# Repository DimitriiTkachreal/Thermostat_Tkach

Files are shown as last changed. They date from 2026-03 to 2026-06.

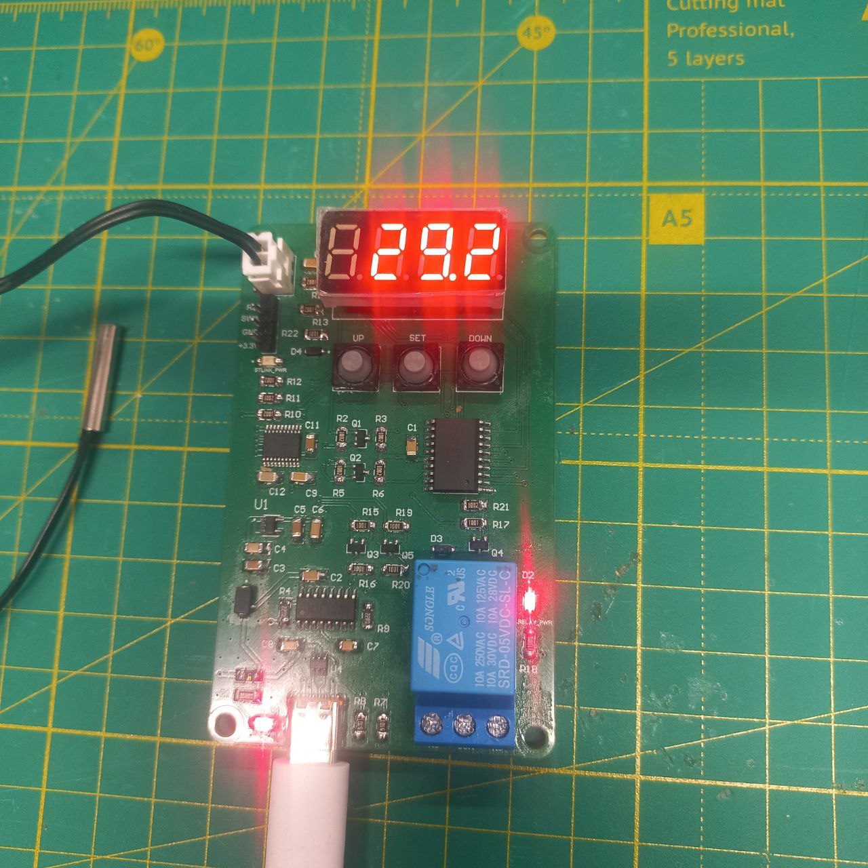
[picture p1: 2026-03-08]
Docs/Photo1.jpg

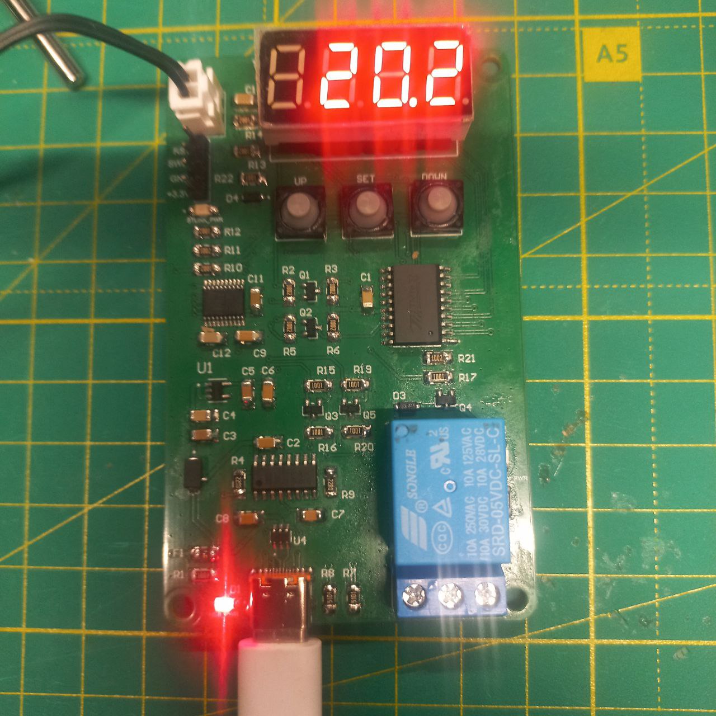
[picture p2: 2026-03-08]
Docs/Photo2.jpg

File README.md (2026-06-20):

# Thermostat STM8 v1.0

**Автор:** Ткач Дімітрій (@ld_td7) | **Email:** lidergsm1466@gmail.com  
**Дата:** 30.08.2025  

## Опис проєкту
Цифровий термостат реального часу на базі 8-бітного мікроконтролера STM8. Проєкт є функціональним аналогом популярного модуля W1209. Прошивка написанау у стилі Bare-Metal мовою C (стандарт C89, компілятор COSMIC) без використання сторонніх бібліотек. Розроблено в рамках стажування Ajax.

### Апаратна частина
* **MCU:** STM8S103F3P6 (16 MHz, 1KB RAM, 8KB Flash, 640 bytes EEPROM).
* **Живлення:** USB Type-C (5V). Логіка мікроконтролера живиться від 3.3V через лінійний стабілізатор AP2112K-3.3TRG1. Для зменшення навантаження на стабілізатор, силова частина та периферія живляться безпосередньо від 5V.
* **Узгодження рівнів:** Оскільки МК працює на 3.3V, а дисплей та UART на 5V, на лініях даних встановлено двонаправлені конвертери логічних рівнів.
* **Сенсор:** NTC термістор 10kΩ (B3950) + резистор 10kΩ (дільник напруги). Підключений до піна **PC4** (АЦП канал 2, вхід налаштовано як Floating).
* **Дисплей:** 4-розрядний 7-сегментний LED-індикатор з драйвером TM1637. Підключений до **PC6 (DIO)** та **PC7 (CLK)**. Піни налаштовані в режим Open-Drain із зовнішніми підтяжками.
* **Керування:** 3 тактові кнопки (SET - **PC5**, UP - **PD2**, DOWN - **PD3**). Налаштовані як Floating входи, оскільки на платі розведені зовнішні підтягуючі резистори 10kΩ до 3.3V.
* **Вихідний каскад:** Електромеханічне реле (керується через пін **PC3**, режим Push-Pull).
* **Дебаг:** Вбудований USB-UART міст CH340C. Прошивання мікроконтролера, через ST-Link v2.

## Інструкція з користування
Керування здійснюється кнопками: `SET`, `UP`, `DOWN`.
У робочому режимі дисплей відображає поточну температуру в приміщенні. Якщо температура виходить за межі встановлених лімітів, МК подає логічну одиницю на реле для увімкнення нагріву/охолодження (загоряється відповідний індикатор). Для швидкої зміни цільової температури коротко натисніть `SET`. Якщо датчик пошкоджено або температура виходить за межі вимірювання, пристрій переходить у захист і відображає `Err` або `ALrM`.

### Меню налаштувань
Для входу у глибокі налаштування утримуйте кнопку **SET** більше **1 секунди**.
* **Навігація:** `UP` / `DOWN` перемикають параметри (P0...P6).
* **Редагування:** Натисніть `SET` для вибору, змініть значення кнопками `UP`/`DOWN`, натисніть `SET` для збереження в енергонезалежну пам'ять.
* **Вихід:** Зачекайте 10 секунд (автовихід).

#### 📋 Карта параметрів
| Код | Назва параметра |  Опис функції І | Фізичний діапазон МК | Заводське |
|:---:|:---|:---|:---:|:---:|
| **P 0** | **Mode** | Режим роботи термостата | `0` (Нагрів) / `1` (Охолодження) | `0` |
| **P 1** | **Hysteresis** | Гістерезис (різниця вкл/викл) | 0.1 ... 15.0 °C | 2.0 °C |
| **P 2** | **Max Limit** | Обмеження максимальної температури | -20.0 ... 120.0 °C | 80.0 °C |
| **P 3** | **Min Limit** | Обмеження мінімальної температури | -20.0 ... 120.0 °C | -20.0 °C |
| **P 4** | **Calibration**| Калібрування похибки датчика | -10.0 ... +10.0 °C | 0.0 °C |
| **P 5** | **Delay** | Затримка ввімкнення (захист компресора)  | 0 ... 10 хв | 0 хв |
| **P 6** | **Alarm** | Температура аварійного вимкнення | -20.0 ... 120.0 °C | 85.0 °C |
| **P 7** | **Reset** | Скидання до заводських налаштувань | `0` (Не скидати) / `1` (скинути) | 0 |

## Структура репозиторію

```text
Thermostat_STM8/
├── Altium/                                  # Апаратна розробка (Altium Designer)
│   ├── Docs/                                # Документація для виробництва
│   ├── Library/                             # Власні бібліотеки компонентів (SchLib/PcbLib)
│   └── Project Outputs/                     # Згенеровані файли (PCB_Therm, Thermostat_STM8)
│
├── Docs/                                    # Виробнича документація
│   ├── Gerber_PCB_Thermostat_STM8/          # Gerber та NC Drill файли для виробництва плати
│   ├── Internal_OutJob_Thermostat_STM8_v1.0.pdf                    # Загальна інформація про апаратну частину
│   └── Thermostat_STM8_BOM_Ajax.xlsx        # Перелік електронних компонентів (BOM)
│
├── Software/                                # Вихідний код (VS Code / Cosmic C)
│   ├── app/                                 # Бізнес-логіка (thermostat.c, ui.c, settings.c)
│   ├── bsp/                                 # Board config (апаратні абстракції пінів)
│   ├── drivers/                             # Драйвери (TM1637, NTC, UART, Buttons)
│   ├── mcu/                                 # HAL (mcu_regs.h, gpio.c, adc.c, timer.c, eeprom.c)
│   ├── core/                                # main.c та stm8_interrupt_vector.c
│   └── platform/                            # Системні заголовки компілятора
│
├── .gitignore                               # Правила ігнорування артефактів збірки
└── README.md                                # Цей документ

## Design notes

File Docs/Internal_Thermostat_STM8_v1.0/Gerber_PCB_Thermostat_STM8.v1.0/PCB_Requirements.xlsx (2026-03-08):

PCB Name | Internal_PCB_Thermostat_STM8_v1.0 |  | <Parameter PCB_Version not found>
Author | Dimitriy Tkach
Amount boards per stand | 1
Produced within | 2 weeks
Item | Requirement | Comment
Layer count | 2
Size | 56 x 90 mm
Thickness | 1.6 mm
Material | FR-4
Min track/spacing | 0.2mm / 10mil
Min hole size | 0.3 mm
Copper weight | 1oz / 35um
Mask | on both sides
Mask color | Green
Castellated holes edges | No
Surfaces finishing | HASL
Silkscreen | YES
Silkscreen color | White
Board Outline, Cutout | Mechanical1 (GM1)
Electric test | Necessarily for 100% samples

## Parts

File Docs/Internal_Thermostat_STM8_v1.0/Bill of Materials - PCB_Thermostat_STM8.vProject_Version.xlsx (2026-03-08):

Internal reference |  |  |  |  |  |  |  |  |  |  |  |  | THERMOSTAT
Assembly variant |  |  |  |  |  |  |  |  |  |  |  |  | 1
Engineer(s) |  |  |  |  |  |  |  |  |  |  |  |  | Tkach
Document timestamp |  |  |  |  |  |  |  |  |  |  |  |  | 2026-02-19
Technical information |  |  |  |  |  |  |  | Additional information |  |  | Logistics information
 |  |  |  |  |  |  |  |  |  |  | Ajax warehouse |  | Replacement options
Designator | Manufacturer | Part Number | Value | Tolerance | Voltage | Component Type | Package | Quantity | Comment | Description | Ajax_1C_ID | Ajax_1C_PN | Replacement
C1, C2, C7, C8, C9, C10, C12 | Yageo | CC1206KRX7R9BB104 | 0.1uF | ±10% | 50V | Capacitor (MLCC) | 1206 | 7 | 100nF | CAP CER 0.1UF 10% 50V X7R 1206 |  |  | NONE
C3, C5 | Hitano | 1206B106K160N2 | 10uF | ±10% | 16V | Capacitor (Tantalum) | 1206 (3216-18) | 2 | 10uF | CAP CER 10UF 10% 16V 1206 |  |  | NONE
C4, C6 | Hitano | C1206B105J500N2 | 1uF | ±10% | 50V | Capacitor (MLCC) | 1206 | 2 | 1uF | CAP CER 1UF 5% 50V X7R 1206 |  |  | NONE
C11 | Yageo | C1206C225K5RACAUTO | 2.2uF | ±10% | 50V | Capacitor (MLCC) | 1206 | 1 | 2.2uF | CAP CER 2.2UF 10% 50V X7R 1206 |  |  | NONE
D1, D2, D5 | Lite-On | LTST-C150KRKT | Red |  |  | LED | 1206 | 3 | Red | LED RED CLEAR CHIP SMD 1206 |  |  | NONE
D3 | Diodes Inc. | 1N4148W-7-F |  |  | 100V | Diode | SOD-123 | 1 | 1N4148W | Diode Switching 100V 300mA |  |  | NONE
D4, D6 | Diodes Zetex | 1N5819HW-7-F |  |  | 40V | Diode Schottky | SOD-123 | 2 | DIODE SCHOTTKY 40V 1A SOD123 | DIODE SCHOTTKY 40V 1A SOD123 |  |  | NONE
F1 | Bourns | MF-NSMF050-2 |  |  |  | PTC | 1206 | 1 | PTC RESET FUSE 13.2V 500MA 1206 | PTC RESET FUSE 13.2V 500MA 1206 |  |  | NONE
DP1 | Xlitx | 3461ВS-1 |  |  |  | Display | TH (Module) | 1 | 4-Digit 7-Seg | 4-Digit 7-Segment Display Module 0.36" CA |  |  | NONE
J1 | GCT | USB4110-GF-A |  |  |  | Connector | USB-C | 1 | USB-C | USB Type-C Receptacle |  |  | NONE
J2 | Degson | DG301-5.0-03P-12-00A |  |  |  | Connector | TH | 1 | Terminal Block | 5mm Pitch Terminal Block |  |  | NONE
J3 | JST | B2B-XH-A |  |  |  | Connector | TH | 1 | XH-2.54 | Conn Header Vert 2pos 2.5mm |  |  | NONE
K1 | Songle | SRD-05VDC-SL-C |  |  | 5V | Relay | TH | 1 | Relay 5V | Relay SPDT 10A 5V |  |  | NONE
P1 | Wurth Elektronik | 61300411121 |  |  |  | Connector | TH | 1 | SWIM Header | Header 2.54mm 4 Pin |  |  | NONE
Q1, Q2, Q3, Q4, Q5 | DIODES INCORPORATED | 2N7002-7-F |  |  | 60V | Transistor (MOSFET) | SOT23-3 | 5 | 2N7002-7-F | MOSFET N-CH 60V 115MA SOT23-3 |  |  | NONE
R2, R3, R5, R6, R10, R11, R12, R13, R14, R21 | Hitano | RC1206JR-10KR | 10k | ±5% |  | Resistor | 1206 | 10 | 10k | RES 10K OHM 5% 0.25W 1206 |  |  | NONE
R7, R8 | Hitano | RC1206JR-5K1R | 5.1k | ±5% |  | Resistor | 1206 | 2 | 5.1k | RES 5.1K OHM 5% 0.25W 1206 |  |  | NONE
R1, R15, R16, R17, R18, R19, R20, R22 | Hitano | RC1206JR-1KR | 1k | ±5% |  | Resistor | 1206 | 8 | 1k | RES 1K OHM 5% 0.25W 1206 |  |  | NONE
R4, R9 | Hitano | RC1206JR-22R | 22R |  |  | Resistor | 1206 | 2 | 22R | RES 22 OHM 5% 0.25W 1206 |  |  | NONE
SW1, SW2, SW3 | Daier | TSX88HN |  |  |  | Switch | TH | 3 | Tact Switch | Switch Tactile SPST-NO 0.02A 15V |  |  | NONE
R21 | Hitano | RC1206JR-100R | 100R | ±5% |  | Resistor | 1206 | 1 | 100R | RES 100 OHM 5% 0.25W 1206 |  |  | NONE
U1 | Diodes Inc. | AP2112K-3.3TRG1 | 3.3V |  |  | IC (REG) | SOT-23-5 | 1 | AP2112K-3.3TRG1 | IC REG LINEAR 3.3V 600MA SOT25 |  |  | NONE
U2 | Titan Micro | TM1637 |  |  |  | IC (Driver) | SOP-20 | 1 | TM1637 | LED Drive Control Special Circuit |  |  | NONE
U3 | WCH | CH340C |  |  |  | IC (Interface) | SOP-16 | 1 | CH340C | USB to Serial Converter |  |  | NONE
U4 | STMicroelectronics | USBLC6-2SC6 |  |  |  | Tvs Diode Surface Mount | SOT-23-6 | 1 | USBLC6-2SC6 | 17V Clamp 5A (8/20Âµs) Ipp Tvs Diode Surface Mount SOT-23-6 |  |  | NONE
U5 | STMicroelectronics | STM8S103F3P6 |  |  |  | IC (MCU) | TSSOP-20 | 1 | STM8S103 | STM8S Access Line 8-bit MCU 16MHz 8KB Flash |  |  | NONE
Sensor_1 | Generic | NTC-10K-3950-XH2.54 | 10k | ±1% |  | Thermistor | Probe | 1 | NTC Probe Thermistor | Waterproof NTC Thermistor 10k 3950 w/ connector XH2.54 |  |  | NONE

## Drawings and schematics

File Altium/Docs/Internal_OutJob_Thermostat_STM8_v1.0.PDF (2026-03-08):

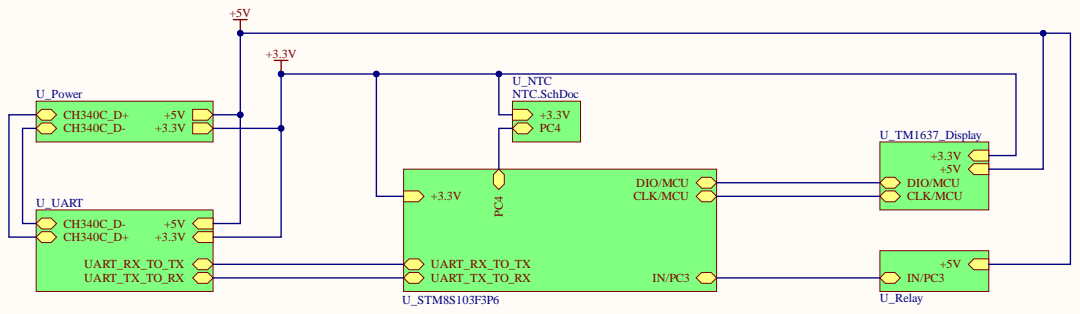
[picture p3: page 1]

U_NTC NTC.SchDoc

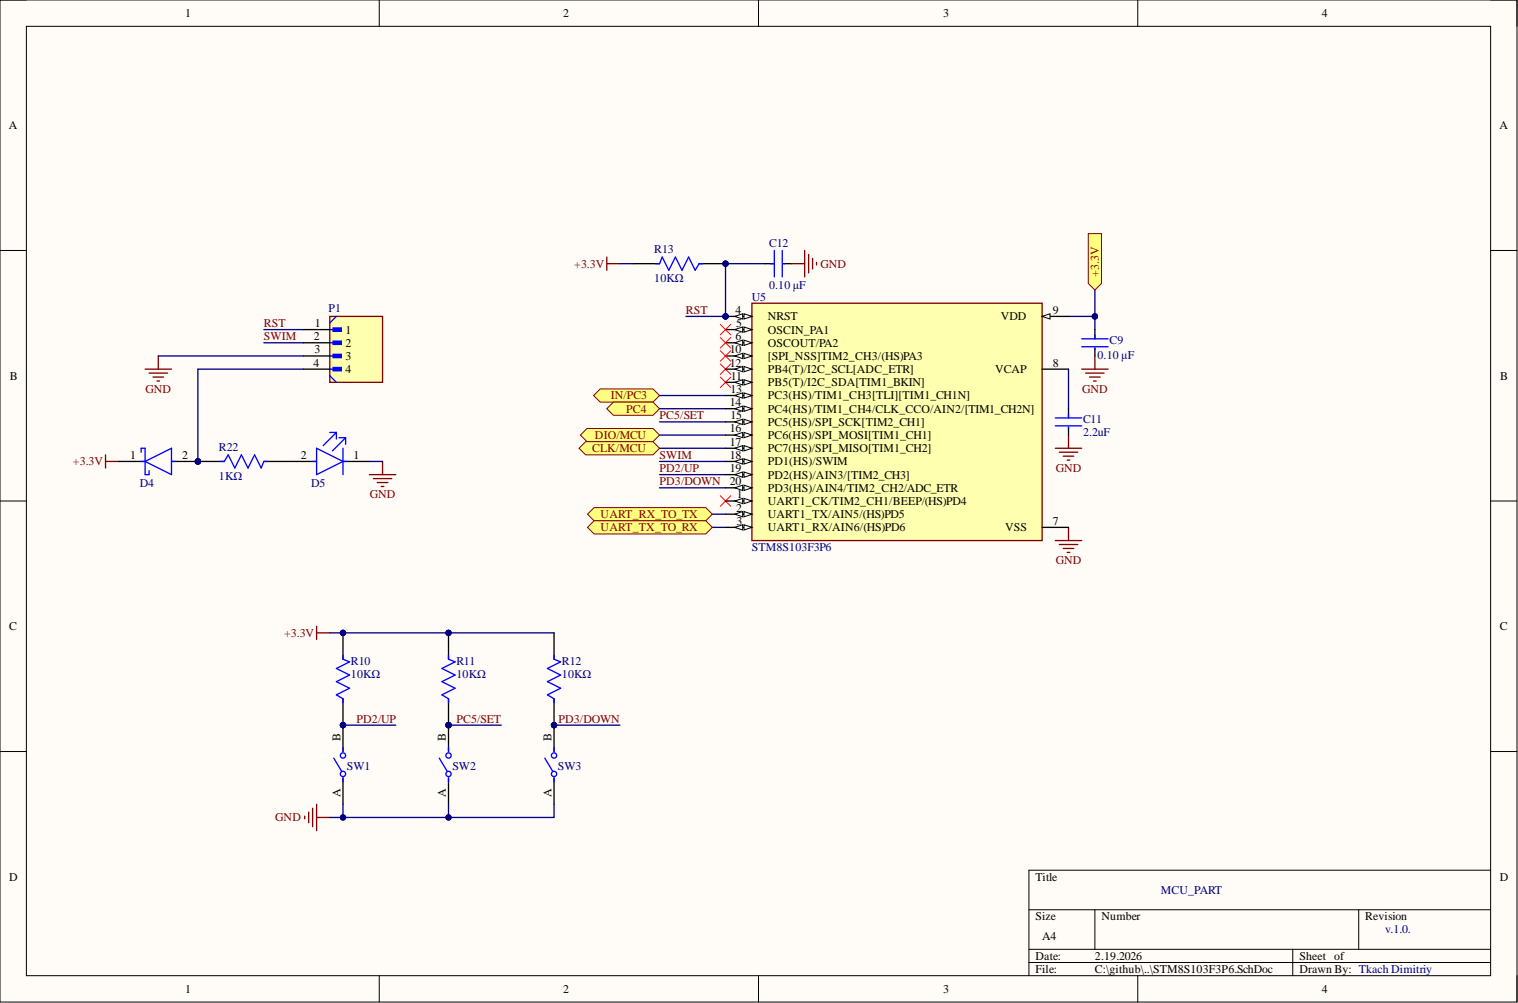
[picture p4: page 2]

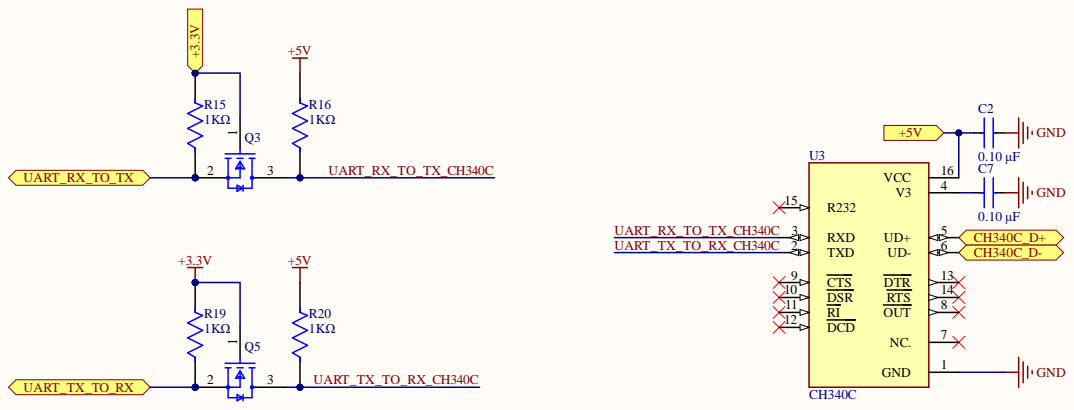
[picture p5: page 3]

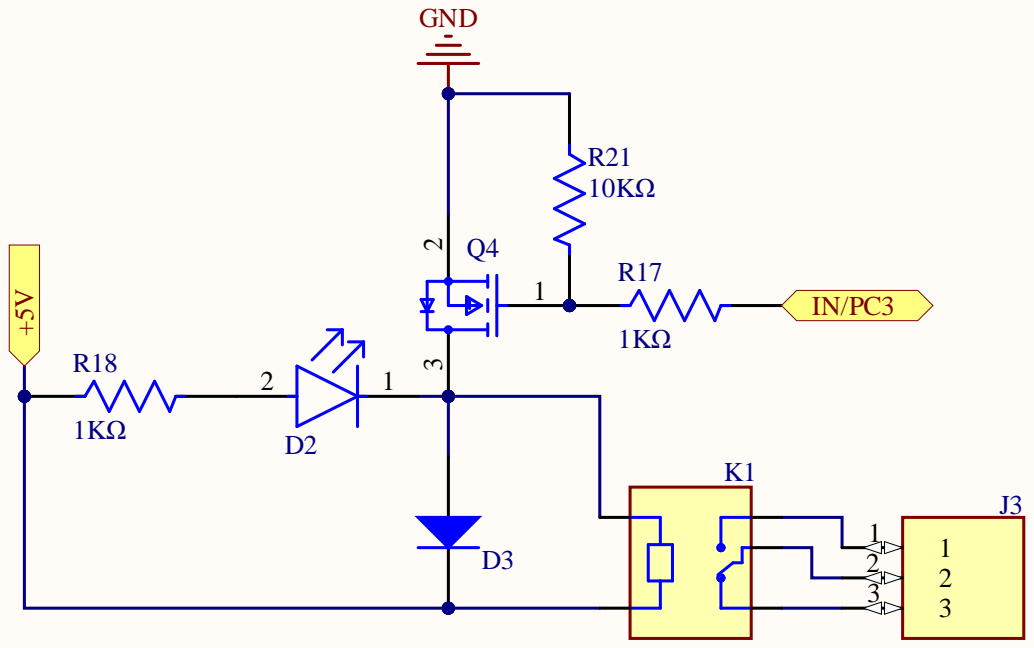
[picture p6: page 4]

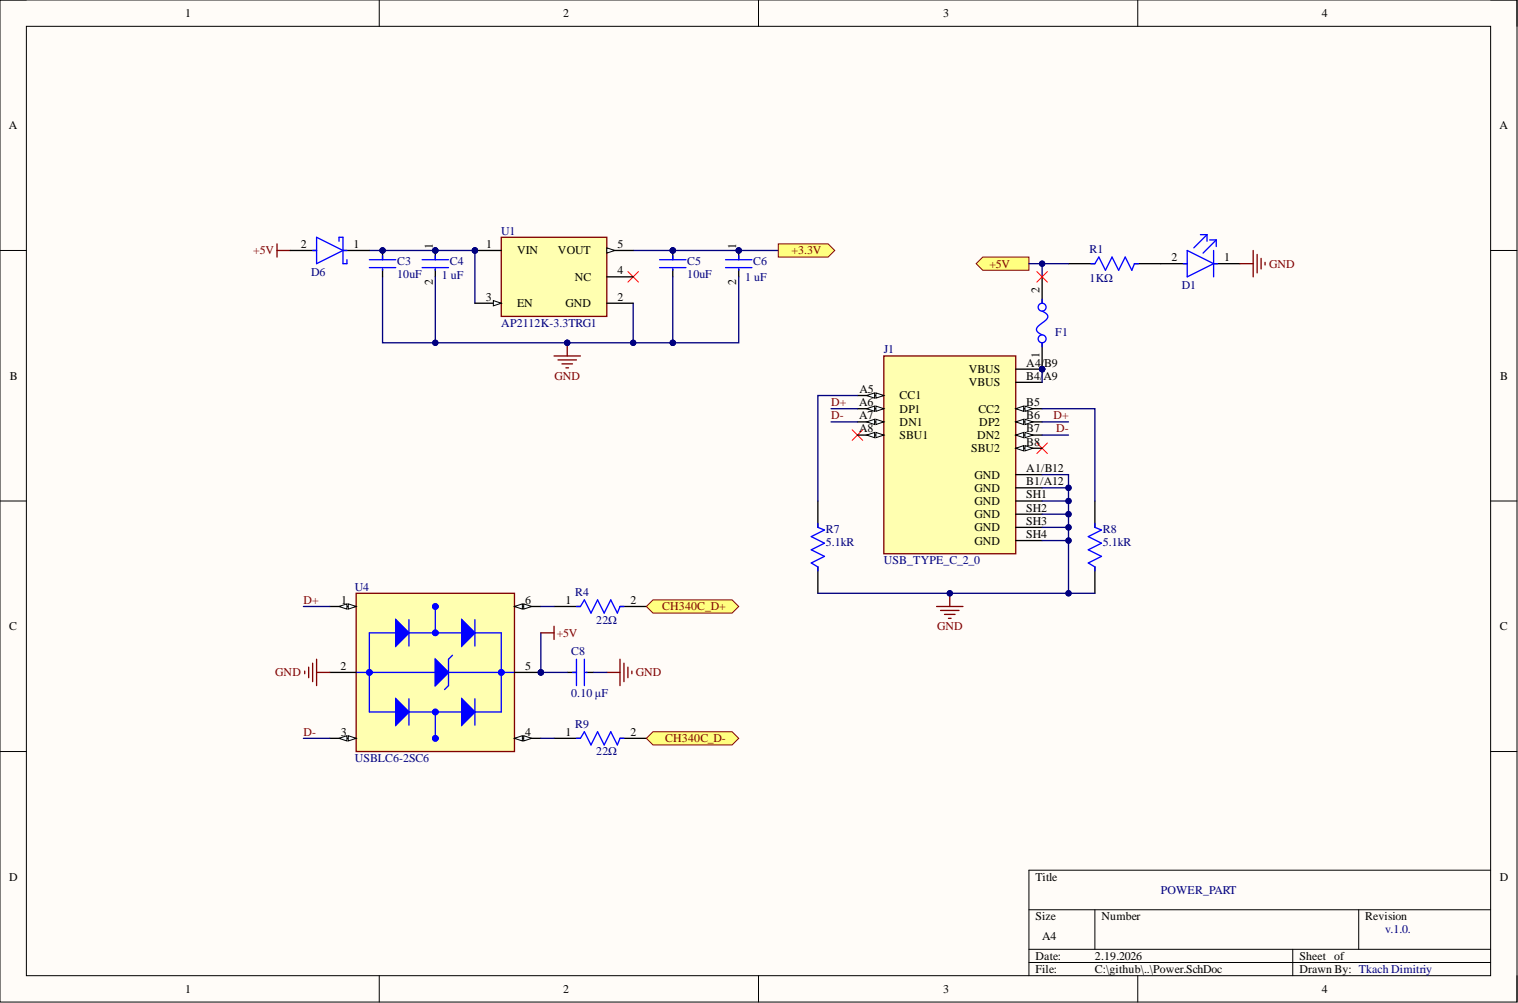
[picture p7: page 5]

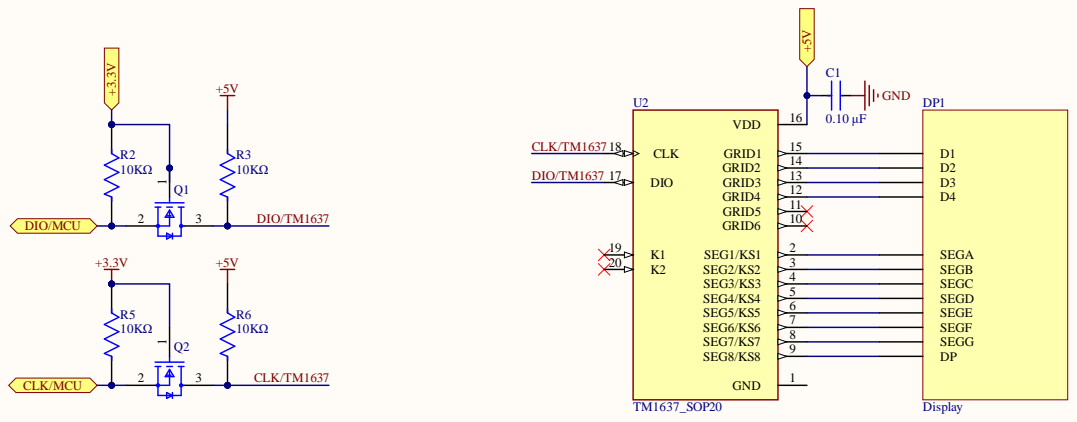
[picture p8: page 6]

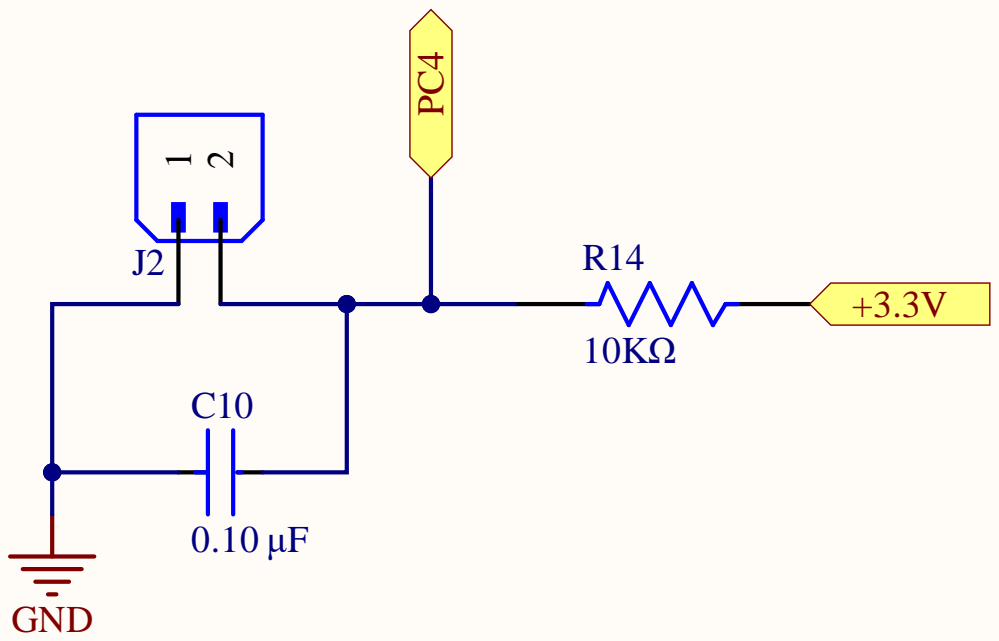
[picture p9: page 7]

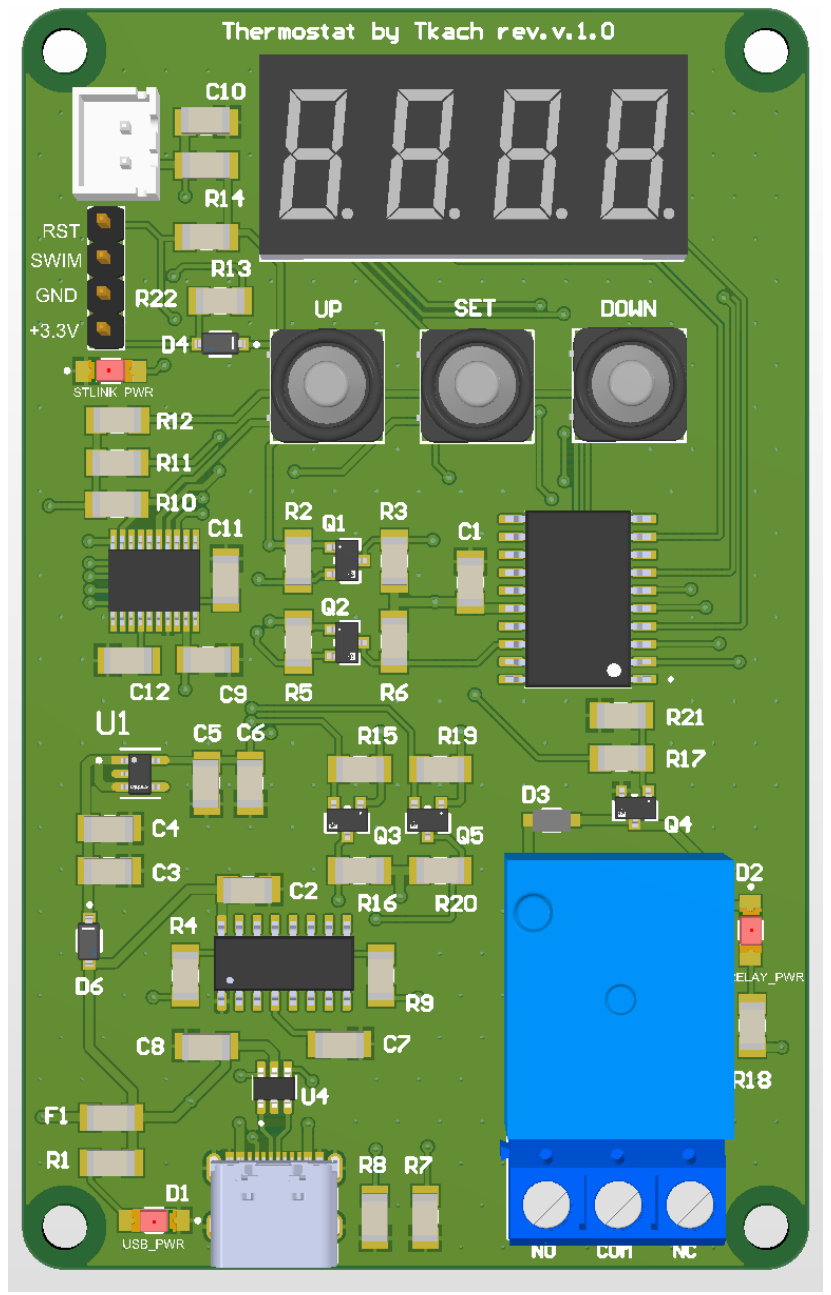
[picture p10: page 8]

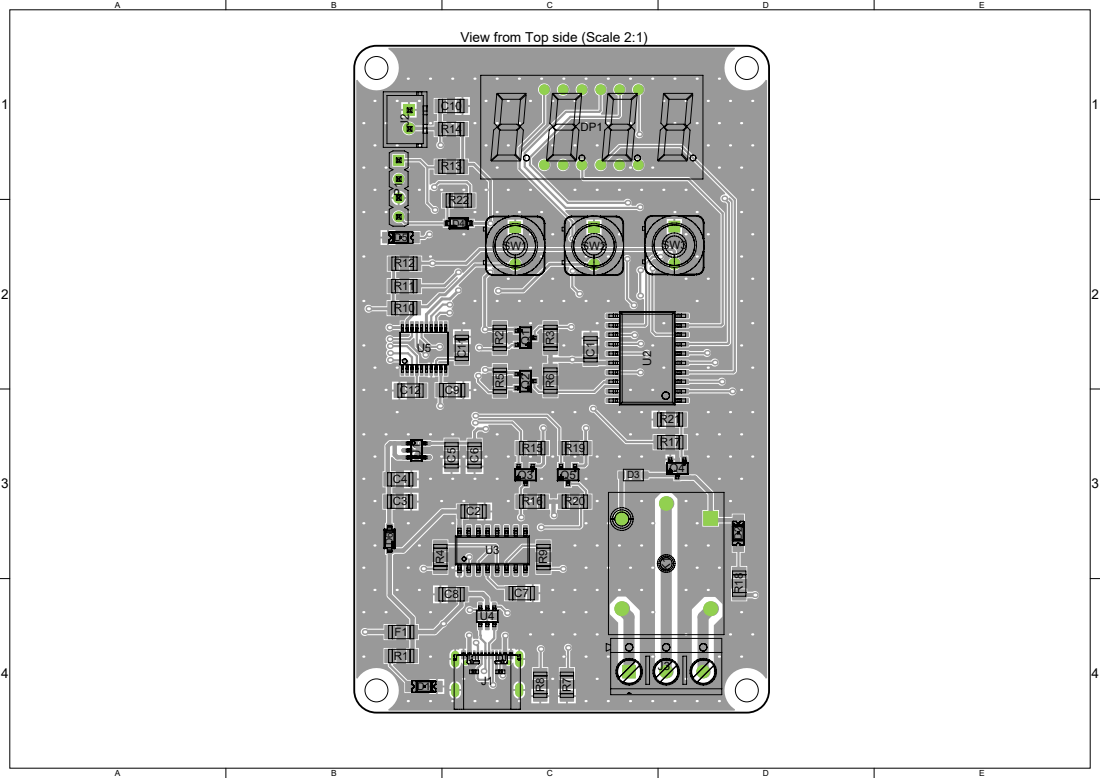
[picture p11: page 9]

View from Top side (Scale 2:1)

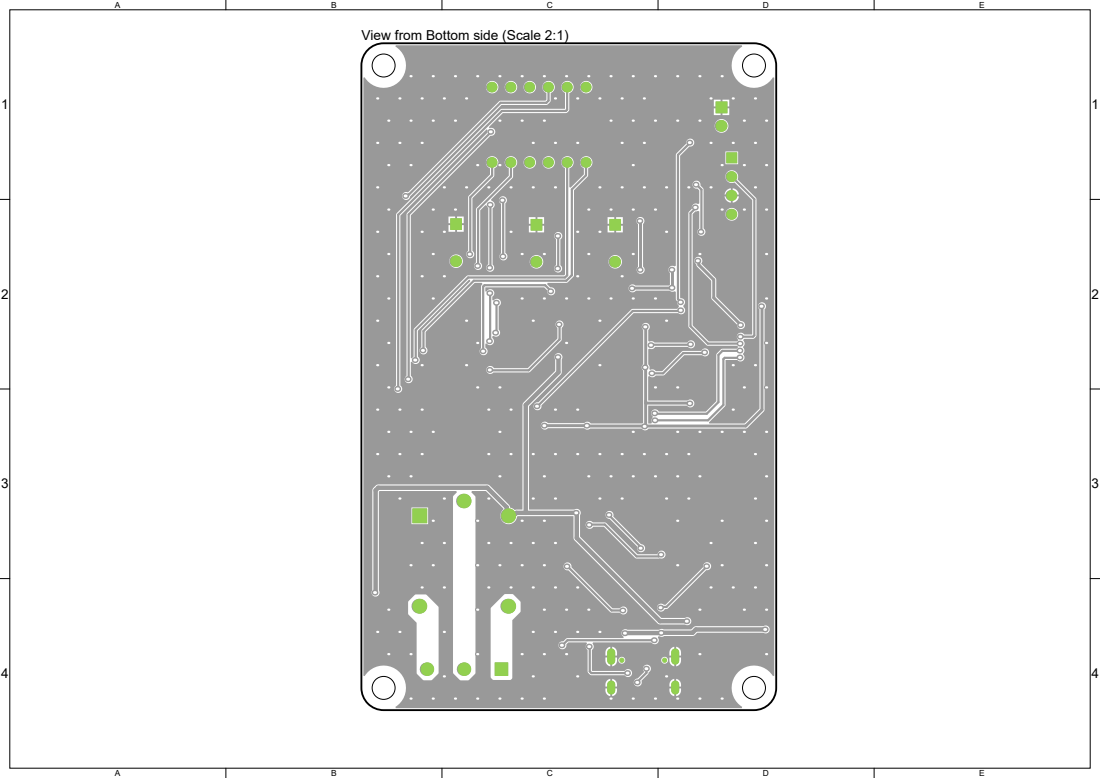
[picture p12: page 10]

View from Bottom side (Scale 2:1)

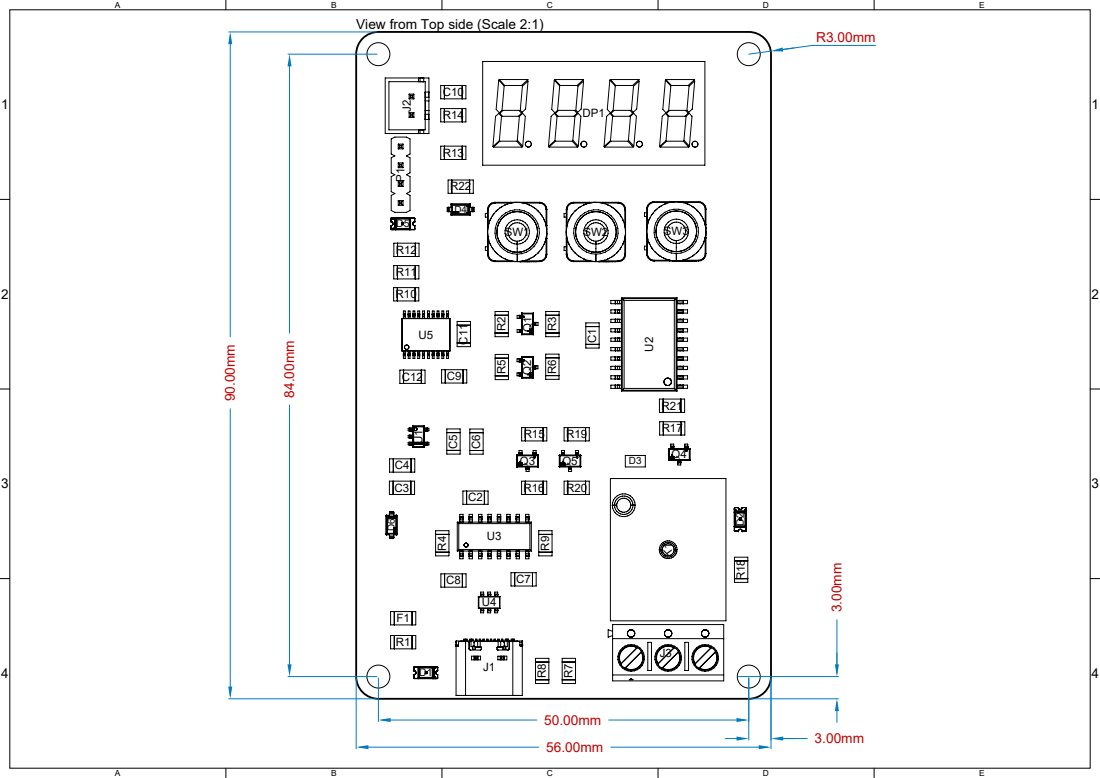
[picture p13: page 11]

View from Top side (Scale 2:1)

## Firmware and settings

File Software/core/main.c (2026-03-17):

/**
 * @file    main.c
 * @brief   Головний файл проєкту (Точка входу).
 * @details Ініціалізує всі модулі та запускає нескінченний цикл опитування (Super-loop).
 */
#include "board_config.h"
#include "clock.h"
#include "gpio.h"
#include "timer.h"
#include "buttons.h"
#include "ntc.h"
#include "adc.h"
#include "tm1637.h"
#include "eeprom.h"
#include "settings.h"
#include "thermostat.h"
#include "ui.h"
#include "uart.h"

/* Змінна для неблокуючої відправки телеметрії (логування) */
static uint32_t last_log_time = 0;
/*Для оновлення дисплея*/
static uint32_t last_ui_update = 0;

void main(void)
{
    /* ====================================================================== */
    /* 1. ІНІЦІАЛІЗАЦІЯ ЗАЛІЗА (Hardware Abstraction Layer)                   */
    /* ====================================================================== */
    /* Важливо: Годинник завжди запускається першим! */
    CLOCK_Init();  
    GPIO_Init();   
    Timer4_Init();  
    UART_Init();   
    ADC_Init();

    _asm("rim");
    
    /* ====================================================================== */
    /* 2. ІНІЦІАЛІЗАЦІЯ БІЗНЕС-ЛОГІКИ (Business Logic Layer)                  */
    /* ====================================================================== */
    /* Важливо: Settings_Init має бути до Thermostat_Init, бо мозок читає EEPROM */
    Settings_Init();     
    Thermostat_Init();   
    UI_Init();   
    
    UI_StartAnimation();//Напис старт

    /* Сигнал у термінал про успішне завантаження (Телеметрія) */
    UART_SendString("\n--- Thermostat Boot OK ---\n");

    /* ====================================================================== */
    /* 3. ГОЛОВНИЙ ЦИКЛ (Super-loop / Round-Robin)                            */
    /* ====================================================================== */
    while (1)
    {
        uint32_t current_time = Timer_GetMillis();

        /* А) Збір даних із зовнішнього світу */
        Buttons_Process();
        if ((current_time - last_ui_update) >= 250) 
        {
        /* Б) Обробка фізики та керування реле */
        Thermostat_Process();
        /* В) Обробка меню та малювання на екрані */
        UI_Process();
        last_ui_update = current_time;
        }
        /* Г) Телеметрія (Відправляємо лог у термінал комп'ютера кожні 2 секунди) */
        current_time = Timer_GetMillis();
        if ((current_time - last_log_time) >= 2000) 
        {
            UART_SendString("T: ");
            UART_SendInt(Thermostat_GetCurrentTemp());
            UART_SendString(" | Set: ");
            UART_SendInt(Settings_Get(PARAM_TARGET_TEMP));
            UART_SendString(" | State: ");
            UART_SendInt((int16_t)Thermostat_GetState());
            UART_SendString("\n");
            
            last_log_time = current_time;
        }
    }
}

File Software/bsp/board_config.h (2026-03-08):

/**
 * @file    board_config.h
 * @brief   Карта підключення апаратної частини (Піни термостата v1.0).
 * @details Базується на принциповій схемі. Всі піни і порти описані тут.
 */

#ifndef BOARD_CONFIG_H
#define BOARD_CONFIG_H

#include "mcu_regs.h"

/* ========================================================================== */
/* 1. ДИСПЛЕЙ TM1637                                                          */
/* ========================================================================== */
/* DIO підключено до PC6, CLK підключено до PC7 */
#define TM1637_PORT_ODR    GPIOC_ODR
#define TM1637_PORT_IDR    GPIOC_IDR
#define TM1637_PORT_DDR    GPIOC_DDR
#define TM1637_PORT_CR1    GPIOC_CR1
#define TM1637_PORT_CR2    GPIOC_CR2

#define TM1637_DIO_PIN     (1 << 6) /* PC6 */
#define TM1637_CLK_PIN     (1 << 7) /* PC7 */

/* ========================================================================== */
/* 2. ТЕРМІСТОР NTC 10K (АЦП)                                                 */
/* ========================================================================== */
/* Підключено до PC4 (Канал АЦП 2) */
#define NTC_ADC_CHANNEL    (1 << 1) /* Двійкове 0010 для регістра CSR */
#define NTC_PORT_DDR       GPIOC_DDR
#define NTC_PORT_CR1       GPIOC_CR1
#define NTC_PORT_CR2       GPIOC_CR2
#define NTC_PIN            (1 << 4) /* Фізичний пін PC4 */

/* ========================================================================== */
/* 3. КНОПКИ КЕРУВАННЯ                                                        */
/* ========================================================================== */
/* UP -> PD2, DOWN -> PD3, SET -> PC5 */
#define BTN_UP_PORT_IDR    GPIOD_IDR
#define BTN_UP_PIN         (1 << 2)

#define BTN_DOWN_PORT_IDR  GPIOD_IDR
#define BTN_DOWN_PIN       (1 << 3)

#define BTN_SET_PORT_IDR   GPIOC_IDR
#define BTN_SET_PIN        (1 << 5)

/* ========================================================================== */
/* 4. РЕЛЕ НАГРІВАЧА/ОХОЛОДЖУВАЧА                                             */
/* ========================================================================== */
/* IN підключено до PC3 */
#define RELAY_PORT_ODR     GPIOC_ODR
#define RELAY_PORT_DDR     GPIOC_DDR
#define RELAY_PORT_CR1     GPIOC_CR1
#define RELAY_PORT_CR2     GPIOC_CR2

#define RELAY_PIN          (1 << 3) /* PC3 */

#endif /* BOARD_CONFIG_H */

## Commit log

2025-08-30 Thermostat was added.
    [DISPLAY.SchLib, Sheet1_Power_MCU.SchDoc, Sheet1_Therm.SchDoc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]
2025-09-02 Update some files
    [Sheet1_Power_MCU.SchDoc, Sheet1_Therm.SchDoc, Thermostat_STM8.PrjPcb]
2025-09-03 update schematichs
    [Sheet1_Therm.SchDoc, Thermostat_STM8.PrjPcb]
2025-09-03 Update schematics.
    [Sheet1_Therm.SchDoc]
2025-09-17 upadate schematics
    [Sheet1_Therm.SchDoc]
2025-10-08 big_update_shematics
    Виконав усі правки, окрім заміни asm1117 на dc-dc. Детальніше в описі проекту
    [HDR-F-2.54_1x3.SchLib, HDR-M-2.54_1x6.SchLib, Sheet1_Therm.SchDoc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]
2025-10-09 Update_scheme
    added logic-level coverter
    [Sheet1_Therm.SchDoc]
2025-10-28 end schme
    [Sheet1_Therm.SchDoc]
2025-10-29 Update_schematics
    This commit completes the schematic design phase and prepares the project for PCB layout.
    Key changes include:
    Standardize Footprints:
    Replaced all 0402/0603 SMD resistors (R1-R10, R12) with the 1206 package size (e.g., RESC3216) for easier manual assembly.
    Replaced all 0402/0603 ceramic capacitors (C1, C4-C12) with the 1206 package size (e.g., CAPC3216).
    Replaced THT electrolytic capacitors (C2, C3) with SMD Tantalum D-Case (T491D107K016AT).
    Component Swaps:
    Replaced the custom THT terminal block (J3, and the deleted J2) with a verified 3-pin Molex pluggable connector (395430603) for improved serviceability.
    (Internal) Verified that TXS0102 symbols (U4, U6) and the USB-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
    [Sheet1_Therm.SchDoc]
2025-11-05 PCB_VERSION_0
    Complete initial PCB layout and routing (0 DRC errors) for Thermostat Tkach
    [LED_DISPLAY.PcbLib, Sheet1_Therm.SchDoc, Thermostat_STM8.PrjPcb]
2025-11-19 feat(pcb/layout): final layout pass, compaction, and mechanical prep
    this commit contains the finalized hardware layout and initial library setup. all components have been reviewed for local ukrainian availability (radiomag/imrad) and standardized to the 1206 package size for manual assembly.
    completed changes: * total pcb compaction. * added 4x m3 mounting holes and finalized board shape with rounded corners. * verified ldo stability components (10uf tantalum) and flyback diode (1n4148w) and updated bom. * successfully swapped tm1637 driver from dip to sop-20 footprint. * resolved all component link mismatch errors between schematic and pcb. * created dedicated component library (pcb lib f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
    [CONECTOR.PcbLib, CONct.SchLib, Components - 18.11.25 - 13.14.SchLib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]
2025-11-19 feat(hardware): finalize PCB layout, silkscreen and add Project Library
    Finalized the PCB design according to all requirements.
    Changes implemented:
    - Completed component placement and routing (compact layout).
    - Updated Silkscreen: arranged designators and added pin labels.
    - Passed Design Rule Check (DRC) with 0 errors.
    - Implemented mentor's feedback:
    * Standardized components to 1206 package.
    * Added mounting holes and rounded board corners.
    * Optimized power planes and thermal relief.
    - Created 'Thermostat_Lib.IntLib' (Integrated Library) containing all project components for offline usage.
    [CONct.SchLib, HDR-F-2.54_1x3.SchLib, HDR-M-2.54_1x6.SchLib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]
2025-11-25 finalize PCB layout v1.0 and establish Cosmic build environment
    Hardware (Altium Designer):
    - Finalized PCB layout: compacted placement, added mounting holes (M3), and defined board shape with rounded corners.
    - Implemented high-density routing strategies and polygon pours (GND/VCC) with Via Stitching.
    - Created project-specific Integrated Library (.IntLib) for offline development.
    - DRC passed with 0 errors.
    Firmware (VS Code & Cosmic):
    - Configured `tasks.json` for automated compilation (cxstm8) and linking (clnk).
    - Solved pathing and shell compatibility issues (using cmd.exe context).
    - Implemented `flash: stvp` task for reliable programming via ST-Link V2 (using STVP CLI).
    - Note: `lau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
    [SEVE_SEG_036INX4.stp, SOP_20.PcbLib, Sheet1_Therm.SchDoc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]
2025-12-03 feat(release): ifinalize production documentation and setup vscode
    Firmware Changes (VS Code & Cosmic):
    - Configured robust build system in `tasks.json`:
    * Compilation: cxstm8 + clnk (Linker script `Linker.lkf` created).
    * Conversion: chex (.sm8 -> .s19).
    * Flashing: Automated task via STVP CLI (ST-Link V2).
    Hardware Documentation (Altium Designer):
    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
    [CONECTOR.PcbLib, DISPLAY.SchLib, PCB_Requirements_PCB_Therm.xlsx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]
2025-12-04 feat(release): finalize PCB design and setup firmware environment
    - Finalized PCB layout v1.0: added 3d model for conector j2 and j3, verified Design Rules (DRC).
    - Generated manufacturing artifacts: Gerber files and NC Drill data.
    - Completed procurement BOM (.xlsx) according to the corporate template (including external NTC probe).
    - Project structure reorganized (`Docs`, `LIB`) and ready for mentor review.
    Firmware (VS Code):
    - Fully configured build system for Cosmic compiler (tasks.json with cmd.exe).
    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
    [PCB_Therm.GBL, PCB_Therm.GBP, PCB_Therm.GBS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]
2025-12-07 pdate PCB manufacturing files (Gerbers + Drill)
    [PCB_Therm.GBL, PCB_Therm.GBP, PCB_Therm.GBS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]
2026-03-08 complete v1.0 hardware design and firmware
    - Transitioned the schematic to a hierarchical structure.
    - Finalized PCB design, configured OutJob for PDF generation (schematic, assembly drawing, 3D).
    - Generated Gerber/NC Drill files, ordered the PCB for manufacturing.
    Software (Firmware):
    - Fully completed the firmware development (Bare-Metal C).
    - Implemented the core thermostat business logic.
    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
    [Bill of Materials - PCB_Thermostat_STM8.vProject_Version.xlsx, Internal_PCB_Thermostat_STM8_v1.0.PcbDoc, Internal_Thermostat_STM8_v1.0.PrjPcb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]
2026-03-17 feat: finalize MVP, add factory reset and fix display logic
    - Implemented factory reset mode for device settings.
    - Updated UI rendering logic to correctly display 3-digit values (hundreds).
    - Performed final hardware and firmware testing.
    - Verified stable system operation in all edge cases.
    Project v1.0 is fully completed.
    [TM1637_Display.SchDoc]
